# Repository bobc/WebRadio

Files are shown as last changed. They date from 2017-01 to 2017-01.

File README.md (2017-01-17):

# ARM Cortex-M3 WebRadio
The ARM WebRadio is an embedded Internet Radio based on an ARM Cortex-M3 Microcontroller and VS1053 Audio Codec.
The VS1053 can decode various audio formats, including Ogg Vorbis, MP3, AAC, WMA, FLAC, WAV, MIDI.

WebRadio

## Features
* Open-Source Hardware
  * Microcontroller: LM3S6950 ARM Cortex-M3 from Luminary Micro / TI
  * Audio Codec: VS1053 from VLSI
  * Display: S65 LCD with 176x132 pixel and 16bit color
  * microSD Socket
  * Rotary Encoder
  * IR Receiver (RC5)
  * PoE (Power over Ethernet)
* Open-Source Software
  * Play Shoutcast/Icecast and RTSP Streams
  * Play audio files from the memory card
  * Alarm Clock

## Hardware and Software
* WebRadio hardware dia
* [Schematics + Layout](https://github.com/watterott/WebRadio/tree/master/hardware)
* [Software/Firmware](https://github.com/watterott/WebRadio/tree/master/software)

## Videos
* [ARM WebRadio test buildup](http://www.youtube.com/watch?v=d3AU1xSci-s)
* [ARM WebRadio v1 prototype](http://www.youtube.com/watch?v=I5wxE6ul4LM)
* [ARM WebRadio v2 demo board](http://www.youtube.com/watch?v=boI7PvBz0HM)
* [ARM WebRadio v3](http://www.youtube.com/watch?v=70_Qk82P8Xw)

## Notes on this fork

The LM3S6950 is obsolete, there is no equivalent.
The S65 LCD may be hard to find as well.

I converted main and exp boards to KiCad 4.0.2.

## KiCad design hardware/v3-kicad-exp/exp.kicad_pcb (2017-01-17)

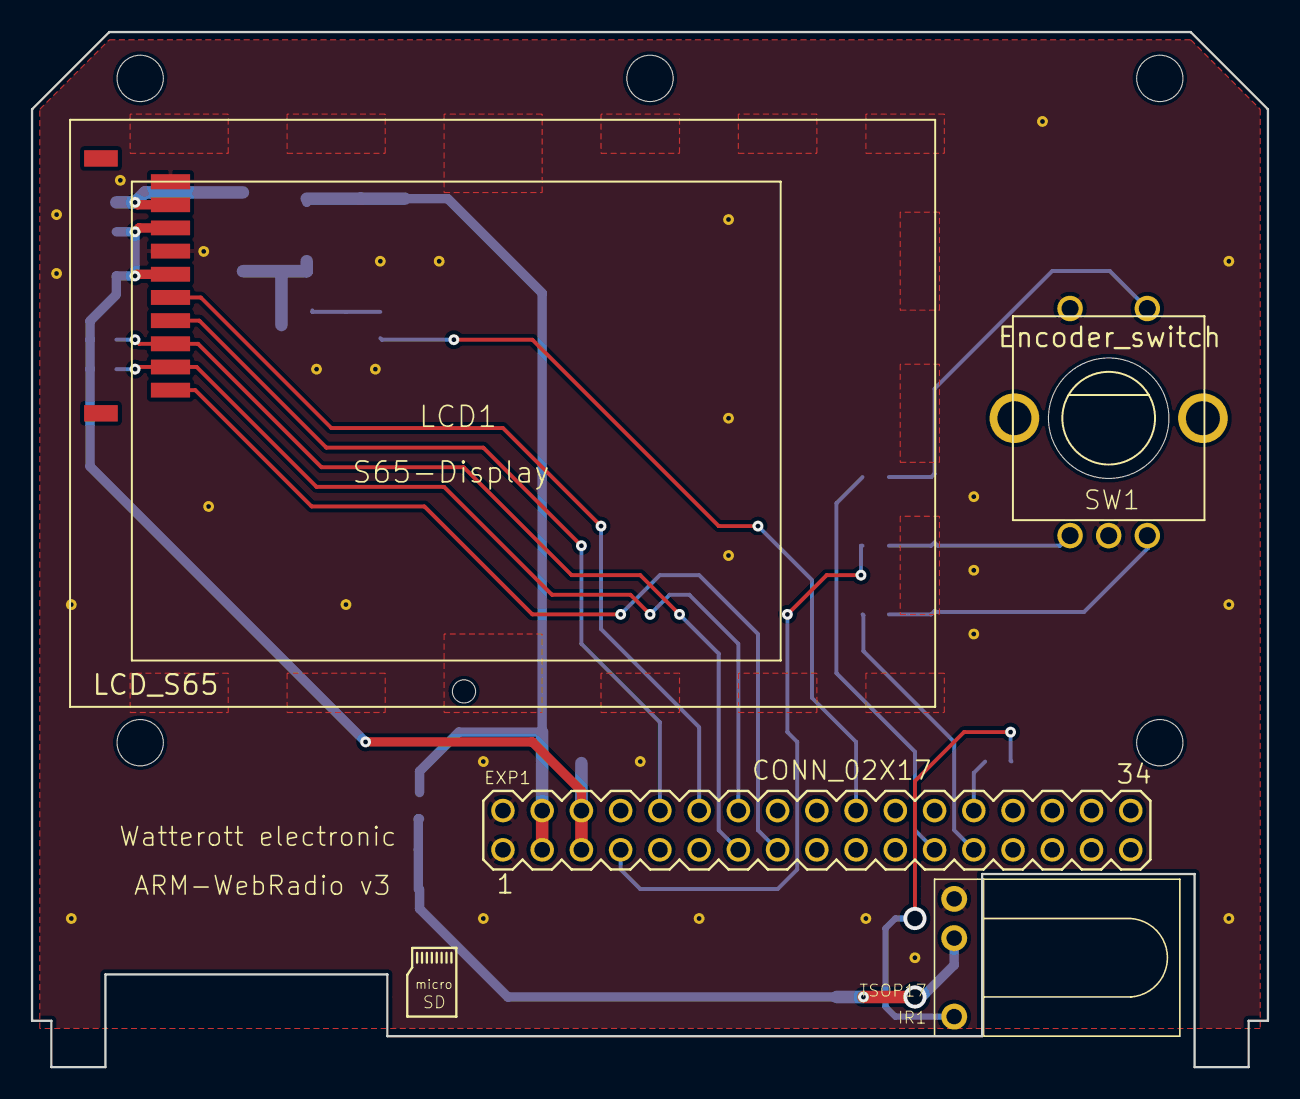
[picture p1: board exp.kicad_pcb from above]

Board: 2 copper layers, 80.0 x 67.0 mm, 63 parts (0 on the bottom side), 21 nets.

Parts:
@HOLE0, @HOLE1, @HOLE2, @HOLE3, @HOLE4, @HOLE5: HOLE
EXP1: CONN_02X17; MA17-2
EXP_C1, EXP_C2: 100nF; C0603
IR1: TSOP17
IR_C1: 100nF; C0603
IR_C2, IR_C3: 2uF; C0603K
IR_R1: 1k; R0603
IR_R2: 100; R0603
LCD1: LCD_S65; S65
LCD_C1, LCD_C2, LCD_C3, LCD_C4: 100nF; C0603
LCD_C5: 2uF; C0603K
LCD_D1: D; DO214AA
LCD_L1: 1-2mH; 50mA; L4532M
LCD_Q1: Q_NMOS_GSD; MICRO3
LCD_R1, LCD_R2, LCD_R4: 47k; R0603
LCD_R3: 100; R0603
SW1: Encoder_switch; ALPS_EC12E_SW
SW_C1, SW_C2, SW_C3: 2.2nF; C0603
SW_R1, SW_R2, SW_R3: 1k; R0603
V1, V2, V3, V4, V5, V6, V7, V8, V9, V10, V11, V12, V13, V14, V15, V16, V17, V18, V19, V20, V21, V22, V23, V24, V25, V26, V27, V28: via

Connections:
+3V3: EXP1.5, EXP1.6, EXP_C2.1, LCD1.1V8, LCD1.2V9, LCD_C1.1, LCD_C2.1, LCD_R1.2, LCD_R2.2
+5V: EXP1.3, EXP1.4, EXP_C1.1, IR_R2.2, LCD_C4.1, LCD_C5.1, LCD_L1.1
/ENC-A: EXP1.25, SW_R1.2
/ENC-B: EXP1.7, SW_R2.1
/ENC-SW: EXP1.23, SW_R3.2
/IR_RX: EXP1.26, IR_R1.1
/LCD_BACKLIGHT_PWM: EXP1.20, LCD_R3.1
/LCD_CS: EXP1.13, LCD1.CS, LCD_R2.1
/LCD_DATA: EXP1.12, LCD1.DATA
/LCD_RESET: EXP1.14, LCD1.RST, LCD_R1.1
/LCD_RS: EXP1.15, LCD1.RS
/LCD_SCK: EXP1.10, LCD1.CLK
GND: EXP1.1, EXP1.2, EXP_C1.2, EXP_C2.2, IR1.GND, IR_C1.2, IR_C2.2, IR_C3.2, LCD1.GND, LCD1.LED-, LCD_C1.2, LCD_C2.2, LCD_C3.2, LCD_C4.2, LCD_C5.2, LCD_Q1.2, LCD_R4.1, SW1.2, SW1.4, SW_C1.2, SW_C2.2, SW_C3.2, V1.1, V2.1, V3.1, V4.1, V5.1, V6.1, V7.1, V8.1, V9.1, V10.1, V11.1, V12.1, V13.1, V14.1, V15.1, V16.1, V17.1, V18.1, V19.1, V20.1, V21.1, V22.1, V23.1, V24.1, V25.1, V26.1, V27.1, V28.1
unnamed: IR1.VO, IR_R1.2
unnamed: IR1.VS, IR_C1.1, IR_C2.1, IR_C3.1, IR_R2.1
unnamed: LCD1.LED+, LCD_C3.1, LCD_D1.1
unnamed: LCD_D1.2, LCD_L1.2, LCD_Q1.3
unnamed: LCD_Q1.1, LCD_R3.2, LCD_R4.2
unnamed: SW1.1, SW_C1.1, SW_R1.1
unnamed: SW1.3, SW_C2.1, SW_R2.2
unnamed: SW1.5, SW_C3.1, SW_R3.1

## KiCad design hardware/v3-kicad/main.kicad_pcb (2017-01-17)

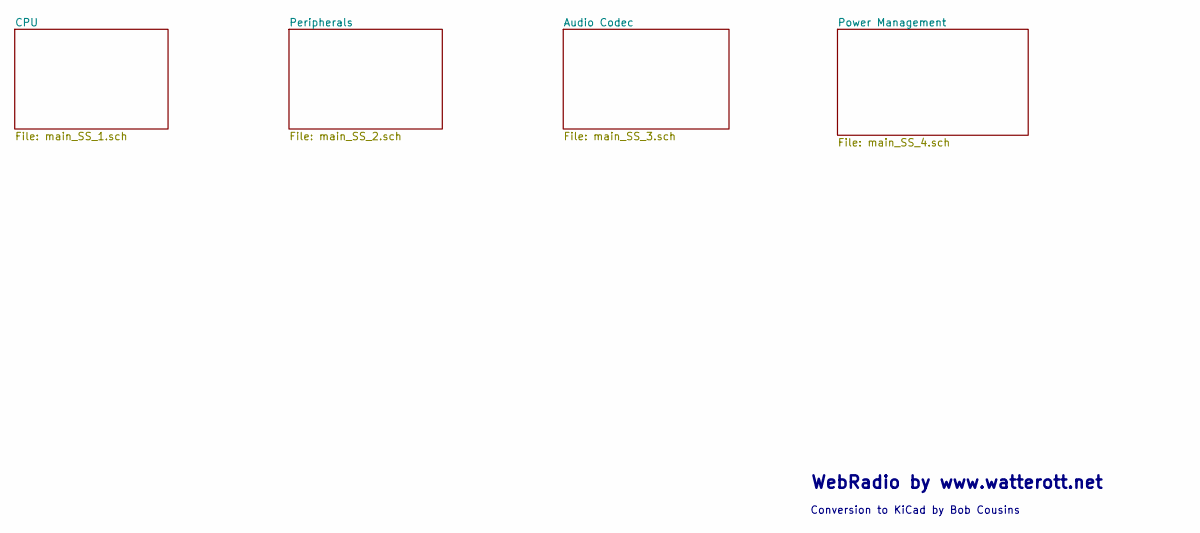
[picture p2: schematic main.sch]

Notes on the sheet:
WebRadio by www.watterott.net
Conversion to KiCad by Bob Cousins

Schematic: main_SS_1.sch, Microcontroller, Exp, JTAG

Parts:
ARM37: LM3S6950; LUMINARY_LQFP100
ARM_C1, ARM_C2, ARM_C3, ARM_C4: 18pF; RCL_C0603
ARM_C5, ARM_C6, ARM_C7, ARM_C8, ARM_C9, ARM_C10, ARM_C11, ARM_C12: 100nF; RCL_C0603
ARM_Q1: 8MHz; CRYSTAL_CS10
ARM_Q2: 25MHz; CRYSTAL_CS10
ARM_R1, ARM_R2, ARM_R3: 10k; RCL_R0603
ARM_R4: 12.4k; RCL_R0603
EXP37: CON-LSTB_MA17-2
EXP_C1, EXP_C2: 100nF; RCL_C0603
JTAG37: CON-LST_MA10-2_SMD
R1, R2: 470*; RCL_R0603
UART2: CON-LSTB_MA06-1
X1, X2, X3, X4: SPECIAL-PAD_SMD-ELLIPSE

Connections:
8: ARM37.70 (I2C0SCL/PB2), EXP37.8
13: ARM37.90 (C0+/C0O/PB6), EXP37.13
25: ARM37.11 (PHA0/PD1), EXP37.25
30: ARM37.22 (C2-/PC7), EXP37.30
+3V3: ARM37.3 (VCCA), ARM37.8 (VCC), ARM37.20 (VCC), ARM37.32 (VCC), ARM37.36 (VCCPHY), ARM37.44 (VCC), ARM37.56 (VCC), ARM37.68 (VCC), ARM37.81 (VCC), ARM37.83 (VCCPHY), ARM37.84 (VCCPHY), ARM37.93 (VCC), ARM37.98 (VCCA), ARM_C5.1, ARM_C6.1, ARM_C7.1, ARM_C8.1, ARM_R1.1, ARM_R2.2, ARM_R3.2, EXP37.5, EXP37.6, EXP_C2.2, JTAG37.1; also elsewhere on the board
+5V: EXP37.3, EXP37.4, EXP_C1.2; also elsewhere on the board
/main_SS_1/7: ARM37.47 (PHB0/PF0), EXP37.7
/main_SS_1/9: ARM37.71 (I2C0SDA/PB3), EXP37.9
/main_SS_1/14: ARM37.91 (C1-/PB5), EXP37.14
/main_SS_1/15: ARM37.92 (C0-/PB4), EXP37.15
/main_SS_1/16: ARM37.95 (CCP0/PD4), EXP37.16
/main_SS_1/17: ARM37.96 (CCP2/PD5), EXP37.17
/main_SS_1/18: ARM37.99 (FAULT/PD6), EXP37.18
/main_SS_1/19: ARM37.100 (IDX0/PD7), EXP37.19
/main_SS_1/20: ARM37.1 (PWM5/PE7), EXP37.20
/main_SS_1/21: ARM37.2 (PWM4/PE6), EXP37.21
/main_SS_1/22: ARM37.5 (PE5), EXP37.22
/main_SS_1/23: ARM37.6 (CCP3/PE4), EXP37.23
/main_SS_1/24: ARM37.10 (PWM0/PD0), EXP37.24
/main_SS_1/26: ARM37.12 (U1RX/PD2), EXP37.26
/main_SS_1/27: ARM37.13 (U1TX/PD3), EXP37.27
/main_SS_1/28: ARM37.18 (U2TX/PG1), EXP37.28, R2.1
/main_SS_1/29: ARM37.19 (U2RX/PG0), EXP37.29, R1.1
/main_SS_1/31: ARM37.23 (C2+/C2O/PC6), EXP37.31
/main_SS_1/32: ARM37.24 (C1+/C1O/PC5), EXP37.32
/main_SS_1/33: ARM37.25 (CCP5/PC4), EXP37.33
/main_SS_1/ERBIAS: ARM37.41 (ERBIAS), ARM_R4.1
/main_SS_1/MDIO: ARM37.58 (MDIO), ARM_R3.1
/main_SS_1/N$9: ARM37.48 (OSC0), ARM_C1.1, ARM_Q1.2
/main_SS_1/N$10: ARM37.49 (OSC1), ARM_C2.1, ARM_Q1.1
/main_SS_1/N$13: ARM37.17 (XTALNPHY), ARM_C4.1, ARM_Q2.1
/main_SS_1/N$14: ARM37.16 (XTALPPHY), ARM_C3.1, ARM_Q2.2
/main_SS_1/RESET: ARM37.64 (~RESET), ARM_R1.2
/main_SS_1/RXD: R2.2, UART2.5
/main_SS_1/TCK: ARM37.80 (TCK/SWCLK/PC0), JTAG37.9
/main_SS_1/TDI: ARM37.78 (TDI/PC2), JTAG37.5
/main_SS_1/TDO: ARM37.77 (TDO/SWO/PC3), JTAG37.13
/main_SS_1/TMS: ARM37.79 (TMS/SWDIO/PC1), JTAG37.7
/main_SS_1/TRST: ARM37.89 (TRST/PB7), ARM_R2.1, JTAG37.3
/main_SS_1/TXD: R1.2, UART2.4
FM_CS: ARM37.73 (SSI1FSS/PE1); also elsewhere on the board
GND: ARM37.4 (GNDA), ARM37.9 (GND), ARM37.15 (GND), ARM37.21 (GND), ARM37.33 (GND), ARM37.39 (GND), ARM37.42 (GNDPHY), ARM37.45 (GND), ARM37.50 (~WAKE), ARM37.54 (GND), ARM37.57 (GND), ARM37.63 (GND), ARM37.65 (CMOD0), ARM37.69 (GND), ARM37.76 (CMOD1), ARM37.82 (GND), ARM37.85 (GNDPHY), ARM37.86 (GNDPHY), ARM37.87 (GND), ARM37.94 (GND), ARM37.97 (GNDA), ARM_C1.2, ARM_C2.2, ARM_C3.2, ARM_C4.2, ARM_C5.2, ARM_C6.2, ARM_C7.2, ARM_C8.2, ARM_C9.2, ARM_C10.2, ARM_C11.2, ARM_C12.2, ARM_R4.2, EXP37.1, EXP37.2, EXP_C1.1, EXP_C2.1, JTAG37.4, JTAG37.6, JTAG37.8, JTAG37.10, JTAG37.12, JTAG37.14, JTAG37.16, JTAG37.18, JTAG37.20, UART2.1; also elsewhere on the board
LED1: ARM37.59 (LED0/PF3); also elsewhere on the board
LED2: ARM37.60 (LED1/PF2); also elsewhere on the board
RD+: ARM37.40 (RXIP); also elsewhere on the board
RD-: ARM37.37 (RXIN); also elsewhere on the board
SCK: ARM37.72 (SSI1CLK/PE0), EXP37.10; also elsewhere on the board
SD_CS: ARM37.67 (PWM3/PB1); also elsewhere on the board
SD_PWR: ARM37.66 (PWM2/PB0); also elsewhere on the board
SI: ARM37.75 (SSI1TX/PE3), EXP37.12; also elsewhere on the board
SO: ARM37.74 (SSI1RX/PE2), EXP37.11; also elsewhere on the board
TD+: ARM37.43 (TXOP); also elsewhere on the board
TD-: ARM37.46 (TXON); also elsewhere on the board
USB_PWR: ARM37.61 (PWM1/PF1); also elsewhere on the board
VCCIO: ARM37.7 (LDO), ARM37.14 (VCC25), ARM37.38 (VCC25), ARM37.62 (VCC25), ARM37.88 (VCC25), ARM_C9.1, ARM_C10.1, ARM_C11.1, ARM_C12.1
VS_CS: ARM37.34 (CCP1/PA6); also elsewhere on the board
VS_DCS: ARM37.29 (SSI0FSS/PA3); also elsewhere on the board
VS_DREQ: ARM37.27 (U0TX/PA1); also elsewhere on the board
VS_RST: ARM37.35 (CCP4/PA7); also elsewhere on the board
VS_SCK: ARM37.28 (SSI0CLK/PA2); also elsewhere on the board
VS_SI: ARM37.31 (SSI0TX/PA5); also elsewhere on the board
VS_SO: ARM37.30 (SSI0RX/PA4); also elsewhere on the board

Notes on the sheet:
CTS
3V3
GND
TxD
RxD
DTR
FTDI Basic Breakout

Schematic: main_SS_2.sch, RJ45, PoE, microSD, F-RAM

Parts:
FM37: FM25V...; RAMTRON_SO8
FM_C1: 100nF; RCL_C0603
FM_R1: 47k; RCL_R0603
POE37: TPS2375D; ETHERNET_SO08
POE_C1: 100nF; RCL_C1206
POE_CLA37: 4,3k; RCL_R0603
POE_D1: SMAJ58A; DIODE_DO214AA
POE_DET37: 24k; RCL_R0603
POE_ILM37: 100k; RCL_R0603
RJ37: RJ45-8-POEWE; ETHERNET_WE_POE
RJ_C1: 100nF; RCL_C0603
RJ_C2, RJ_C5, RJ_C6, RJ_C9: 10pF; RCL_C0603
RJ_C3, RJ_C4, RJ_C7, RJ_C8, RJ_C10: 10nF; RCL_C0603
RJ_R1, RJ_R2, RJ_R3, RJ_R4: 50; RCL_R0603
RJ_R5, RJ_R6: 470; RCL_R0603
RJ_R7: 100; RCL_R0603
SD37: MICRO-SD; SD-CARD_MICRO-SD
SD_C1, SD_C2: 100nF; RCL_C0603
SD_C3: 2uF; RCL_C0603
SD_Q1: P-CHN; IRF-SOT23_MICRO3
SD_R1, SD_R2, SD_R3, SD_R4, SD_R5: 47k; RCL_R0603

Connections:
+3V3: FM37.3 (-WP), FM37.7 (-HOLD), FM37.8 (VCC), FM_C1.1, FM_R1.2, RJ37.3 (RCT), RJ37.4 (TCT), RJ37.L1_P (LED1+), RJ37.L2_P (LED2+), RJ_C1.1, RJ_C3.2, RJ_C4.2, RJ_C7.2, RJ_C8.2, RJ_R1.2, RJ_R2.2, RJ_R3.2, RJ_R4.2, SD_C2.2, SD_C3.2, SD_Q1.2 (S), SD_R1.1; also elsewhere on the board
/main_SS_2/CLASS: POE37.2 (CLASS), POE_CLA37.2
/main_SS_2/DET: POE37.3 (DET), POE_DET37.2
/main_SS_2/ILM: POE37.1 (ILM), POE_ILM37.2
/main_SS_2/N$4: RJ37.L2_N (LED2-), RJ_R6.1
/main_SS_2/N$5: RJ37.L1_N (LED1-), RJ_R5.1
/main_SS_2/N$29: RJ_C10.1, RJ_R7.1
/main_SS_2/POE-: POE37.4 (POE-), POE_C1.2, POE_CLA37.1, POE_D1.A, POE_ILM37.1, RJ37.10 (POE-)
/main_SS_2/SD_1: SD37.1, SD_R5.2
/main_SS_2/SD_3V3: SD37.4, SD_C1.1, SD_Q1.3 (D), SD_R2.1, SD_R3.1, SD_R4.1, SD_R5.1
/main_SS_2/SD_8: SD37.8, SD_R2.2
/main_SS_2/SHIELD: RJ37.NC0 (SHIELD), RJ37.NC1 (SHIELD), RJ_R7.2
FM_CS: FM37.1 (-CS), FM_R1.1; also elsewhere on the board
GND: FM37.4 (GND), FM_C1.2, POE37.5 (RTN), RJ_C1.2, RJ_C2.1, RJ_C3.1, RJ_C4.1, RJ_C5.1, RJ_C6.1, RJ_C7.1, RJ_C8.1, RJ_C9.1, RJ_C10.2, SD37.6, SD_C1.2, SD_C2.1, SD_C3.1; also elsewhere on the board
LED1: RJ_R5.2; also elsewhere on the board
LED2: RJ_R6.2; also elsewhere on the board
POE+: RJ37.9 (POE+); also elsewhere on the board
PWR+: POE37.8 (POE+), POE_C1.1, POE_D1.C, POE_DET37.1; also elsewhere on the board
RD+: RJ37.1 (RD+), RJ_C2.2, RJ_R1.1; also elsewhere on the board
RD-: RJ37.2 (RD-), RJ_C5.2, RJ_R2.1; also elsewhere on the board
SCK: FM37.6 (CLK), SD37.5; also elsewhere on the board
SD_CS: SD37.2, SD_R4.2; also elsewhere on the board
SD_PWR: SD_Q1.1 (G), SD_R1.2; also elsewhere on the board
SI: FM37.5 (DI), SD37.3; also elsewhere on the board
SO: FM37.2 (DO), SD37.7, SD_R3.2; also elsewhere on the board
TD+: RJ37.5 (TD+), RJ_C6.2, RJ_R3.1; also elsewhere on the board
TD-: RJ37.6 (TD-), RJ_C9.2, RJ_R4.1; also elsewhere on the board

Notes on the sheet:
RJ45 + PoE
F-RAM (optional)
4k4
100k
25k
microSD

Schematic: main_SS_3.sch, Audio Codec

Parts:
I2S37: CON-LSTB_MA04-1
OUT37: 1503_09; AUDIO_1503_09
PWR37: CON-LSTB_MA04-1
PWR_C1, PWR_C2: 100nF; RCL_C0603
VS37: VS1053; VLSI_LQFP-48
VS_C1, VS_C2: 27pF; RCL_C0603
VS_C3, VS_C4: 10nF; RCL_C0603
VS_C5: 47nF; RCL_C0603
VS_C6: 1uF; RCL_C0603
VS_C7, VS_C8, VS_C9, VS_C10, VS_C11, VS_C12, VS_C13, VS_C14, VS_C15: 100nF; RCL_C0603
VS_CL2: 2.2nF; RCL_C0603
VS_CL37: 10uF; RCL_C1210
VS_CR2: 2.2nF; RCL_C0603
VS_CR37: 10uF; RCL_C1210
VS_GBUF37: 0*; RCL_R0603
VS_GND37: 0*; RCL_R0603
VS_Q1: 12.288MHz; CRYSTAL_SM49
VS_R1: 1M; RCL_R0603
VS_R2, VS_R3, VS_R9, VS_R10, VS_R11, VS_R12: 100k; RCL_R0603
VS_R4, VS_R5: 22; RCL_R0603
VS_R6: 10; RCL_R0603
VS_R7, VS_R8: 10k; RCL_R0603
VS_RL37: 470; RCL_R0603
VS_RR37: 470; RCL_R0603

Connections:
+1V8: VS37.5 (CVCC0), VS37.7 (CVCC1), VS37.24 (CVCC2), VS37.31 (CVCC3), VS_C10.1, VS_C11.1, VS_C12.1, VS_C13.1; also elsewhere on the board
+2V8: VS37.38 (AVCC0), VS37.43 (AVCC1), VS37.45 (AVCC2), VS_C14.1, VS_C15.1; also elsewhere on the board
+3V3: PWR37.2, PWR_C1.2, VS37.6 (IOVCC0), VS37.14 (IOVCC1), VS37.19 (IOVCC2), VS37.26 (RX), VS37.32 (TEST), VS_C7.1, VS_C8.1, VS_C9.1; also elsewhere on the board
+5V: PWR37.1, PWR_C2.2; also elsewhere on the board
/main_SS_3/GBUF: VS37.42 (GBUF), VS_GBUF37.1, VS_R6.2
/main_SS_3/I2S_LROUT: I2S37.1, VS37.36 (GPIO4), VS_R9.1
/main_SS_3/I2S_MCLK: I2S37.2, VS37.25 (GPIO5), VS_R10.1
/main_SS_3/I2S_SCLK: I2S37.3, VS37.11 (GPIO6), VS_R11.1
/main_SS_3/I2S_SDATA: I2S37.4, VS37.12 (GPIO7), VS_R12.1
/main_SS_3/LEFT: VS37.46 (LEFT), VS_R4.2, VS_RL37.1
/main_SS_3/N$3: VS37.33 (GPIO0), VS37.34 (GPIO1), VS_R3.2
/main_SS_3/N$6: VS37.9 (GPIO2), VS37.10 (GPIO3), VS_R2.2
/main_SS_3/N$8: VS37.18 (XTALI), VS_C2.1, VS_Q1.1, VS_R1.2
/main_SS_3/N$11: VS37.17 (XTALO), VS_C1.1, VS_Q1.2, VS_R1.1
/main_SS_3/N$18: OUT37.1, VS_GBUF37.2, VS_GND37.1
/main_SS_3/N$19: OUT37.3, OUT37.5, VS_CR37.2, VS_R7.1
/main_SS_3/N$20: OUT37.2, OUT37.4, VS_CL37.2, VS_R8.1
/main_SS_3/N$21: VS_CR2.1, VS_CR37.1, VS_RR37.2
/main_SS_3/N$22: VS_CL2.1, VS_CL37.1, VS_RL37.2
/main_SS_3/N$31: VS_C3.2, VS_R4.1
/main_SS_3/N$32: VS_C4.2, VS_R5.1
/main_SS_3/N$33: VS_C5.2, VS_R6.1
/main_SS_3/RCAP: VS37.44 (RCAP), VS_C6.2
/main_SS_3/RIGHT: VS37.39 (RIGHT), VS_R5.2, VS_RR37.1
AGND: VS37.37 (AGND0), VS37.40 (AGND1), VS37.41 (AGND2), VS37.47 (AGND3), VS_C3.1, VS_C4.1, VS_C5.1, VS_C6.1, VS_C14.2, VS_C15.2, VS_CL2.2, VS_CR2.2, VS_GND37.2, VS_R7.2, VS_R8.2; also elsewhere on the board
GND: PWR37.3, PWR37.4, PWR_C1.1, PWR_C2.1, VS37.4 (GND0), VS37.16 (GND1), VS37.20 (GND2), VS37.21 (GND3), VS37.22 (GND4), VS37.35 (GND5), VS_C1.2, VS_C2.2, VS_C7.2, VS_C8.2, VS_C9.2, VS_C10.2, VS_C11.2, VS_C12.2, VS_C13.2, VS_R2.1, VS_R3.1, VS_R9.2, VS_R10.2, VS_R11.2, VS_R12.2; also elsewhere on the board
VS_CS: VS37.23 (~CS); also elsewhere on the board
VS_DCS: VS37.13 (~DCS); also elsewhere on the board
VS_DREQ: VS37.8 (~DREQ); also elsewhere on the board
VS_RST: VS37.3 (~RESET); also elsewhere on the board
VS_SCK: VS37.28 (SCLK); also elsewhere on the board
VS_SI: VS37.29 (SI); also elsewhere on the board
VS_SO: VS37.30 (SO); also elsewhere on the board

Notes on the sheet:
Normal Line-Out
Line-Out for Headphones
VS_GND
VS_GBUF
VS_RR
VS_RL
VS_CL
VS_CR
not mounted
470
10uF
shorted
VS_CR2
VS_CL2
2.2nF
Note: For VS1033 U4 has to be a 2.5V regulator.
Line-Out = green
(Dont use with USB powered speakers)
Further Infos: VLSI AppNote: Connecting analog outputs
GND-AGND

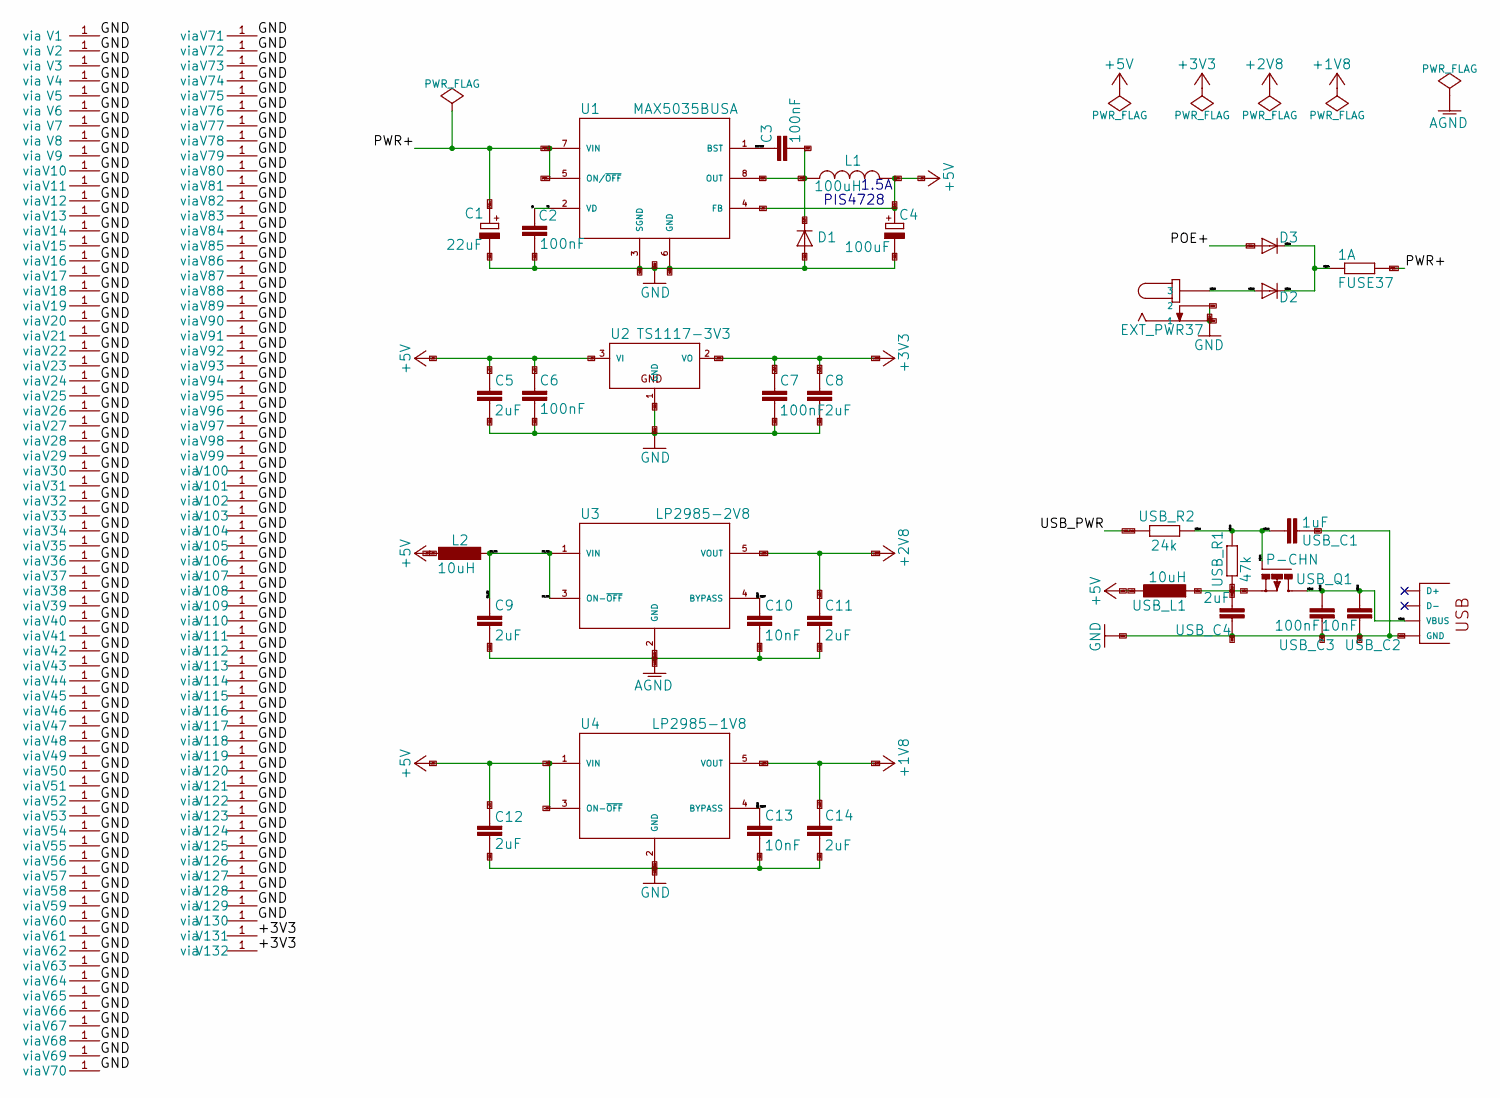
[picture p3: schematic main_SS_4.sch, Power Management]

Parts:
C1: 22uF; RCL_153CLV-0810
C2, C3, C6, C7: 100nF; RCL_C0603
C4: 100uF; RCL_153CLV-0810
C5, C8, C9, C11, C12, C14: 2uF; RCL_C0603
C10, C13: 10nF; RCL_C0603
D1, D2, D3: DIODE_DO214AA
EXT_PWR37: CON-JACK_SPC4077
FUSE37: 1A; RCL_R1206
L1: 100uH; VOLTAGE-REG_CDRH
L2: 10uH; RCL_L3230M
U1: MAX5035BUSA; VOLTAGE-REG_SO8
U2: TS1117-3V3; VOLTAGE-REG_SOT223
U3: LP2985-2V8; VOLTAGE-REG_SOT23-5
U4: LP2985-1V8; VOLTAGE-REG_SOT23-5
USB37: USB-A-S; CON-USB_USB-A-S
USB_C1: 1uF; RCL_C0603
USB_C2: 10nF; RCL_C0603
USB_C3: 100nF; RCL_C0603
USB_C4: 2uF; RCL_C0805
USB_L1: 10uH; RCL_L3230M
USB_Q1: P-CHN; IRF-SOT23_MICRO3
USB_R1: 47k; RCL_R0603
USB_R2: 24k; RCL_R0603
V1, V2, V3, V4, V5, V6, V7, V8, V9, V10, V11, V12, V13, V14, V15, V16, V17, V18, V19, V20, V21, V22, V23, V24, V25, V26, V27, V28, V29, V30, V31, V32, V33, V34, V35, V36, V37, V38, V39, V40, V41, V42, V43, V44, V45, V46, V47, V48, V49, V50, V51, V52, V53, V54, V55, V56, V57, V58, V59, V60, V61, V62, V63, V64, V65, V66, V67, V68, V69, V70, V71, V72, V73, V74, V75, V76, V77, V78, V79, V80, V81, V82, V83, V84, V85, V86, V87, V88, V89, V90, V91, V92, V93, V94, V95, V96, V97, V98, V99, V100, V101, V102, V103, V104, V105, V106, V107, V108, V109, V110, V111, V112, V113, V114, V115, V116, V117, V118, V119, V120, V121, V122, V123, V124, V125, V126, V127, V128, V129, V130, V131, V132: via

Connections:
+1V8: C14.1, U4.5 (VOUT); also elsewhere on the board
+2V8: C11.1, U3.5 (VOUT); also elsewhere on the board
+3V3: C7.1, C8.1, U2.2 (VO), V131.1, V132.1; also elsewhere on the board
+5V: C4.+, C5.1, C6.2, C12.2, L1.2, L2.1, U1.4 (FB), U2.3 (VI), U4.1 (VIN), U4.3 (ON-~OFF), USB_L1.1; also elsewhere on the board
/main_SS_4/5V_VIN: C9.2, L2.2, U3.1 (VIN), U3.3 (ON-~OFF)
/main_SS_4/BST: C3.1, U1.1 (BST)
/main_SS_4/N$12: USB37.VBUS, USB_C2.1, USB_C3.1, USB_Q1.3 (D)
/main_SS_4/N$16: USB_C1.2, USB_Q1.1 (G), USB_R1.2, USB_R2.1
/main_SS_4/N$23: D2.A, EXT_PWR37.3
/main_SS_4/N$24: D2.C, D3.C, FUSE37.1
/main_SS_4/N$27: C10.1, U3.4 (BYPASS)
/main_SS_4/N$28: C13.1, U4.4 (BYPASS)
/main_SS_4/VD: C2.1, U1.2 (VD)
AGND: C9.1, C10.2, C11.2, U3.2 (GND); also elsewhere on the board
GND: C1.-, C2.2, C4.-, C5.2, C6.1, C7.2, C8.2, C12.1, C13.2, C14.2, D1.A, EXT_PWR37.1, EXT_PWR37.2, U1.3 (SGND), U1.6 (GND), U2.1 (GND), U4.2 (GND), USB37.GND, USB_C1.1, USB_C2.2, USB_C3.2, USB_C4.1, V1.1, V2.1, V3.1, V4.1, V5.1, V6.1, V7.1, V8.1, V9.1, V10.1, V11.1, V12.1, V13.1, V14.1, V15.1, V16.1, V17.1, V18.1, V19.1, V20.1, V21.1, V22.1, V23.1, V24.1, V25.1, V26.1, V27.1, V28.1, V29.1, V30.1, V31.1, V32.1, V33.1, V34.1, V35.1, V36.1, V37.1, V38.1, V39.1, V40.1, V41.1, V42.1, V43.1, V44.1, V45.1, V46.1, V47.1, V48.1, V49.1, V50.1, V51.1, V52.1, V53.1, V54.1, V55.1, V56.1, V57.1, V58.1, V59.1, V60.1, V61.1, V62.1, V63.1, V64.1, V65.1, V66.1, V67.1, V68.1, V69.1, V70.1, V71.1, V72.1, V73.1, V74.1, V75.1, V76.1, V77.1, V78.1, V79.1, V80.1, V81.1, V82.1, V83.1, V84.1, V85.1, V86.1, V87.1, V88.1, V89.1, V90.1, V91.1, V92.1, V93.1, V94.1, V95.1, V96.1, V97.1, V98.1, V99.1, V100.1, V101.1, V102.1, V103.1, V104.1, V105.1, V106.1, V107.1, V108.1, V109.1, V110.1, V111.1, V112.1, V113.1, V114.1, V115.1, V116.1, V117.1, V118.1, V119.1, V120.1, V121.1, V122.1, V123.1, V124.1, V125.1, V126.1, V127.1, V128.1, V129.1, V130.1; also elsewhere on the board
unnamed: USB_C4.2, USB_L1.2, USB_Q1.2 (S), USB_R1.1
OUT: C3.2, D1.C, L1.1, U1.8 (OUT)
POE+: D3.A; also elsewhere on the board
PWR+: C1.+, FUSE37.2, U1.5 (ON/~OFF), U1.7 (VIN); also elsewhere on the board
USB_PWR: USB_R2.2; also elsewhere on the board

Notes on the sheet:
1.5A
PIS4728

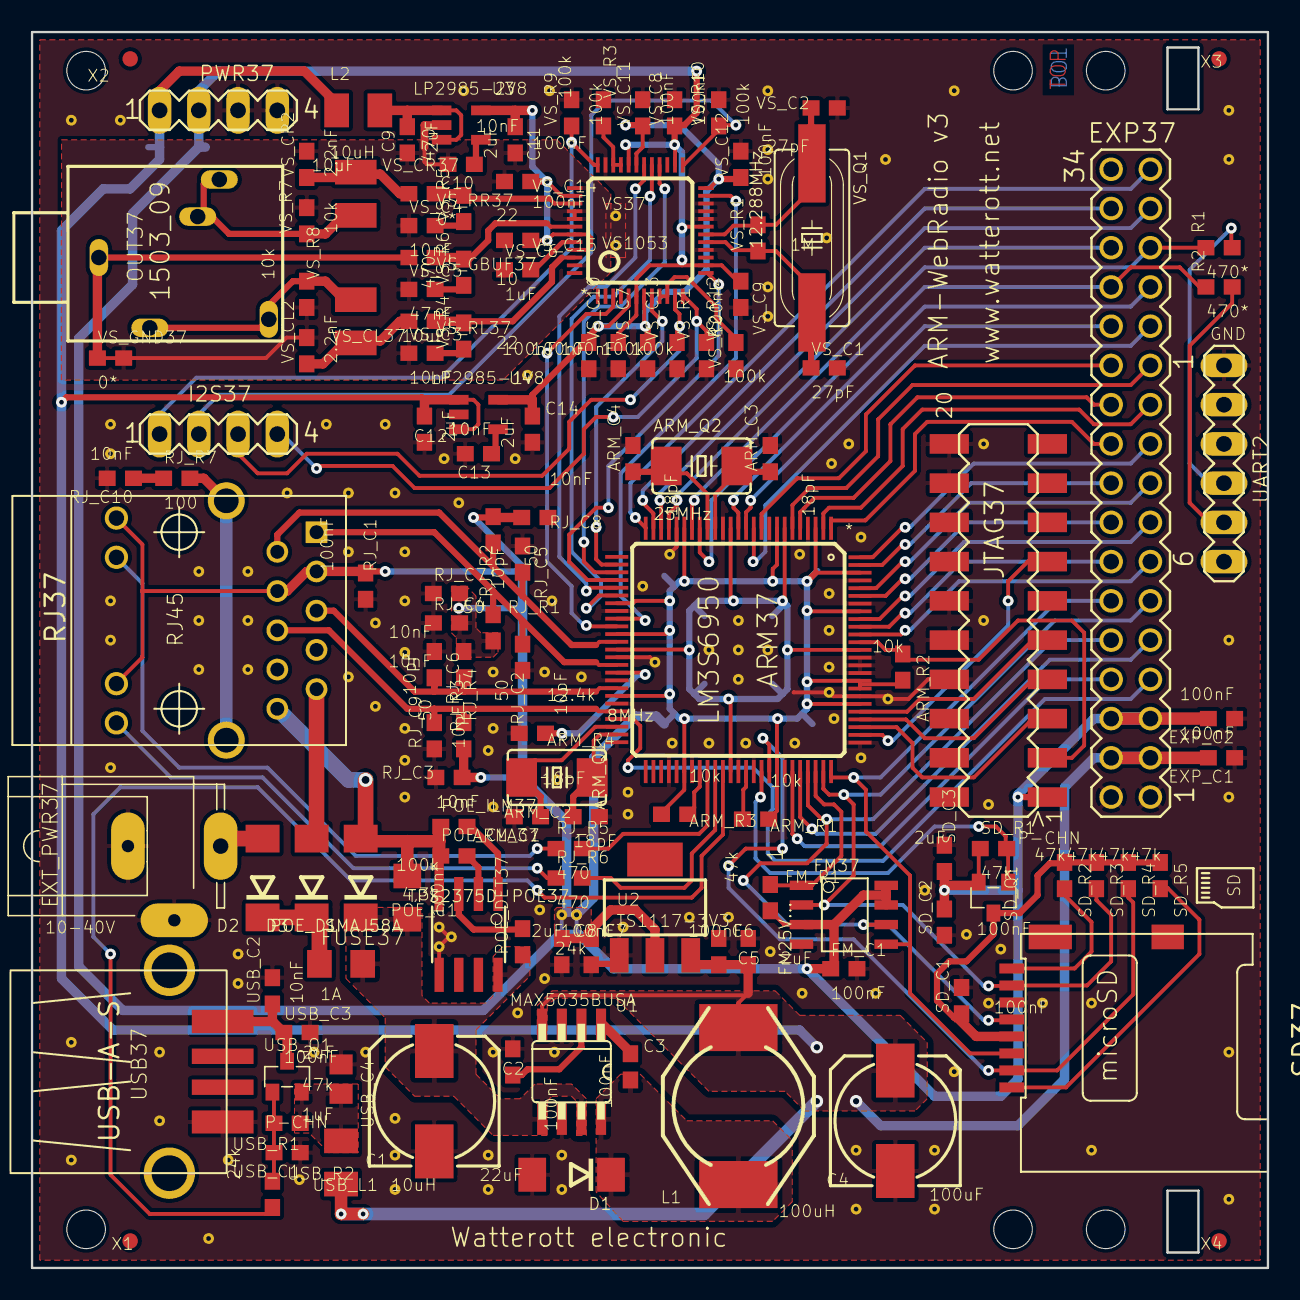
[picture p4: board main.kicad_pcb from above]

Board: 2 copper layers, 80.0 x 80.0 mm, 281 parts (0 on the bottom side), 109 nets.

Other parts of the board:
@HOLE0, @HOLE1, @HOLE2, @HOLE3, @HOLE4, @HOLE5: (no value)

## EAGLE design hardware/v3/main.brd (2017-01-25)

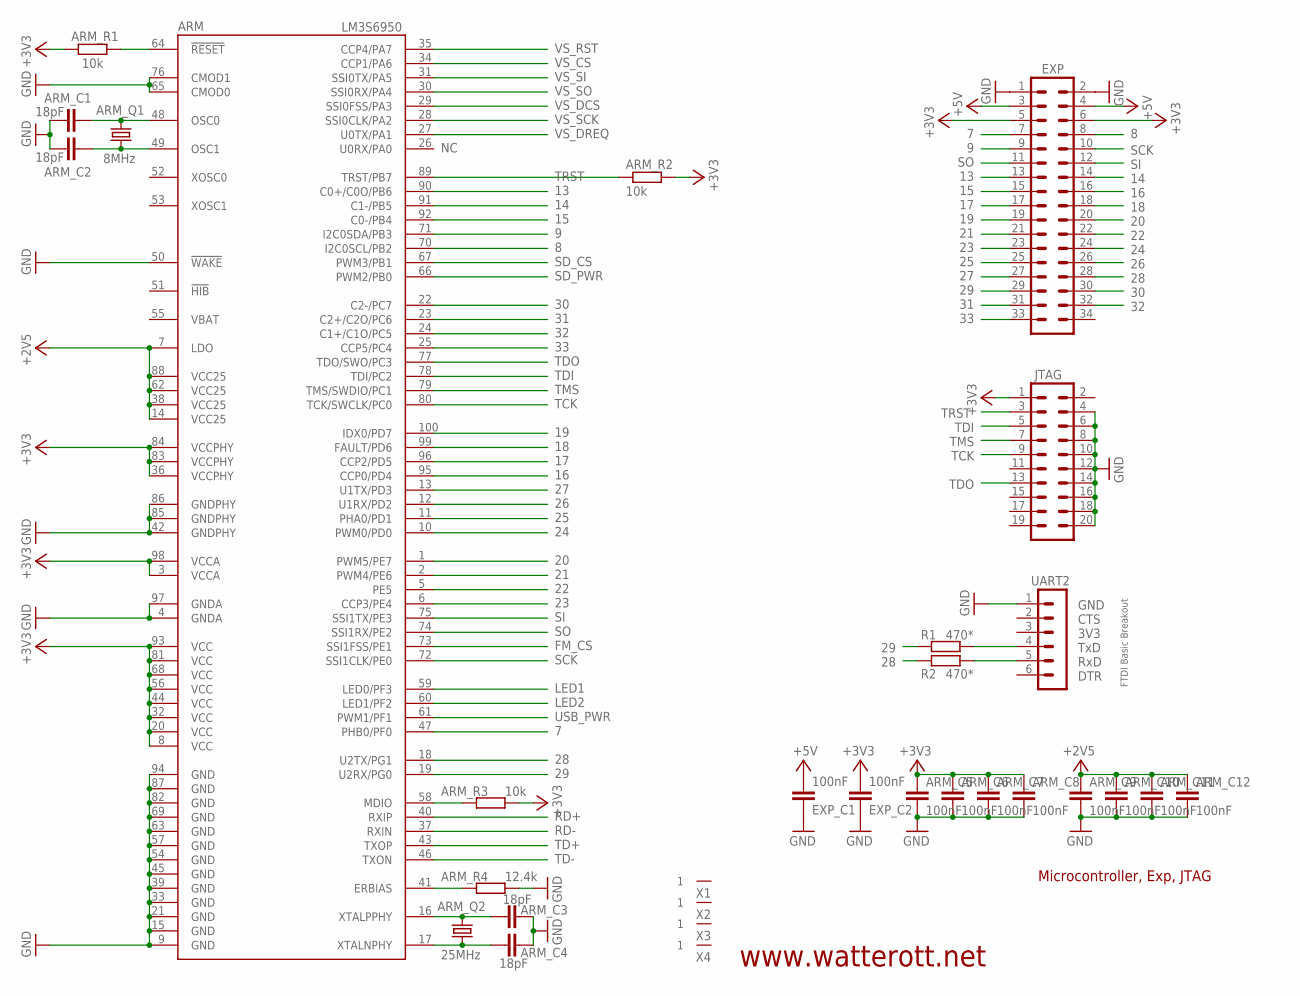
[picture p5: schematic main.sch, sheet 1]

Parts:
ARM: LM3S6950; LQFP100
ARM_C1, ARM_C2, ARM_C3, ARM_C4: 18pF; C0603
ARM_C5, ARM_C6, ARM_C7, ARM_C8, ARM_C9, ARM_C10, ARM_C11, ARM_C12: 100nF; C0603
ARM_Q1: 8MHz; CS10
ARM_Q2: 25MHz; CS10
ARM_R1, ARM_R2, ARM_R3: 10k; R0603
ARM_R4: 12.4k; R0603
EXP: MA17-2
EXP_C1, EXP_C2: 100nF; C0603
JTAG: MA10-2SMD; MA10-2_SMD
R1, R2: 470*; R0603
UART2: MA06-1
X1, X2, X3, X4: ELLIPTICAL-PADS; SMD-ELLIPSE

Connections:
7: ARM.47 (PHB0/PF0), EXP.7
8: ARM.70 (I2C0SCL/PB2), EXP.8
9: ARM.71 (I2C0SDA/PB3), EXP.9
13: ARM.90 (C0+/C0O/PB6), EXP.13
14: ARM.91 (C1-/PB5), EXP.14
15: ARM.92 (C0-/PB4), EXP.15
16: ARM.95 (CCP0/PD4), EXP.16
17: ARM.96 (CCP2/PD5), EXP.17
18: ARM.99 (FAULT/PD6), EXP.18
19: ARM.100 (IDX0/PD7), EXP.19
20: ARM.1 (PWM5/PE7), EXP.20
21: ARM.2 (PWM4/PE6), EXP.21
22: ARM.5 (PE5), EXP.22
23: ARM.6 (CCP3/PE4), EXP.23
24: ARM.10 (PWM0/PD0), EXP.24
25: ARM.11 (PHA0/PD1), EXP.25
26: ARM.12 (U1RX/PD2), EXP.26
27: ARM.13 (U1TX/PD3), EXP.27
28: ARM.18 (U2TX/PG1), EXP.28, R2.1
29: ARM.19 (U2RX/PG0), EXP.29, R1.1
30: ARM.22 (C2-/PC7), EXP.30
31: ARM.23 (C2+/C2O/PC6), EXP.31
32: ARM.24 (C1+/C1O/PC5), EXP.32
33: ARM.25 (CCP5/PC4), EXP.33
+2V5: ARM.7 (LDO), ARM.14 (VCC25), ARM.38 (VCC25), ARM.62 (VCC25), ARM.88 (VCC25), ARM_C9.1, ARM_C10.1, ARM_C11.1, ARM_C12.1
+3V3: ARM.3 (VCCA), ARM.8 (VCC), ARM.20 (VCC), ARM.32 (VCC), ARM.36 (VCCPHY), ARM.44 (VCC), ARM.56 (VCC), ARM.68 (VCC), ARM.81 (VCC), ARM.83 (VCCPHY), ARM.84 (VCCPHY), ARM.93 (VCC), ARM.98 (VCCA), ARM_C5.1, ARM_C6.1, ARM_C7.1, ARM_C8.1, ARM_R1.1, ARM_R2.2, ARM_R3.2, EXP.5, EXP.6, EXP_C2.2, JTAG.1; also elsewhere on the board
+5V: EXP.3, EXP.4, EXP_C1.2; also elsewhere on the board
ERBIAS: ARM.41 (ERBIAS), ARM_R4.1
FM_CS: ARM.73 (SSI1FSS/PE1); also elsewhere on the board
GND: ARM.4 (GNDA), ARM.9 (GND), ARM.15 (GND), ARM.21 (GND), ARM.33 (GND), ARM.39 (GND), ARM.42 (GNDPHY), ARM.45 (GND), ARM.50 (!WAKE), ARM.54 (GND), ARM.57 (GND), ARM.63 (GND), ARM.65 (CMOD0), ARM.69 (GND), ARM.76 (CMOD1), ARM.82 (GND), ARM.85 (GNDPHY), ARM.86 (GNDPHY), ARM.87 (GND), ARM.94 (GND), ARM.97 (GNDA), ARM_C1.2, ARM_C2.2, ARM_C3.2, ARM_C4.2, ARM_C5.2, ARM_C6.2, ARM_C7.2, ARM_C8.2, ARM_C9.2, ARM_C10.2, ARM_C11.2, ARM_C12.2, ARM_R4.2, EXP.1, EXP.2, EXP_C1.1, EXP_C2.1, JTAG.4, JTAG.6, JTAG.8, JTAG.10, JTAG.12, JTAG.14, JTAG.16, JTAG.18, JTAG.20, UART2.1; also elsewhere on the board
LED1: ARM.59 (LED0/PF3); also elsewhere on the board
LED2: ARM.60 (LED1/PF2); also elsewhere on the board
MDIO: ARM.58 (MDIO), ARM_R3.1
unnamed: ARM.48 (OSC0), ARM_C1.1, ARM_Q1.2
unnamed: ARM.49 (OSC1), ARM_C2.1, ARM_Q1.1
unnamed: ARM.17 (XTALNPHY), ARM_C4.1, ARM_Q2.1
unnamed: ARM.16 (XTALPPHY), ARM_C3.1, ARM_Q2.2
RD+: ARM.40 (RXIP); also elsewhere on the board
RD-: ARM.37 (RXIN); also elsewhere on the board
RESET: ARM.64 (!RESET), ARM_R1.2
RXD: R2.2, UART2.5
SCK: ARM.72 (SSI1CLK/PE0), EXP.10; also elsewhere on the board
SD_CS: ARM.67 (PWM3/PB1); also elsewhere on the board
SD_PWR: ARM.66 (PWM2/PB0); also elsewhere on the board
SI: ARM.75 (SSI1TX/PE3), EXP.12; also elsewhere on the board
SO: ARM.74 (SSI1RX/PE2), EXP.11; also elsewhere on the board
TCK: ARM.80 (TCK/SWCLK/PC0), JTAG.9
TD+: ARM.43 (TXOP); also elsewhere on the board
TD-: ARM.46 (TXON); also elsewhere on the board
TDI: ARM.78 (TDI/PC2), JTAG.5
TDO: ARM.77 (TDO/SWO/PC3), JTAG.13
TMS: ARM.79 (TMS/SWDIO/PC1), JTAG.7
TRST: ARM.89 (TRST/PB7), ARM_R2.1, JTAG.3
TXD: R1.2, UART2.4
USB_PWR: ARM.61 (PWM1/PF1); also elsewhere on the board
VBAT: ARM.55 (VBAT)
VS_CS: ARM.34 (CCP1/PA6); also elsewhere on the board
VS_DCS: ARM.29 (SSI0FSS/PA3); also elsewhere on the board
VS_DREQ: ARM.27 (U0TX/PA1); also elsewhere on the board
VS_RST: ARM.35 (CCP4/PA7); also elsewhere on the board
VS_SCK: ARM.28 (SSI0CLK/PA2); also elsewhere on the board
VS_SI: ARM.31 (SSI0TX/PA5); also elsewhere on the board
VS_SO: ARM.30 (SSI0RX/PA4); also elsewhere on the board

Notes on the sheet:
Microcontroller, Exp, JTAG
www.watterott.net
CTS
3V3
GND
TxD
RxD
DTR
FTDI Basic Breakout

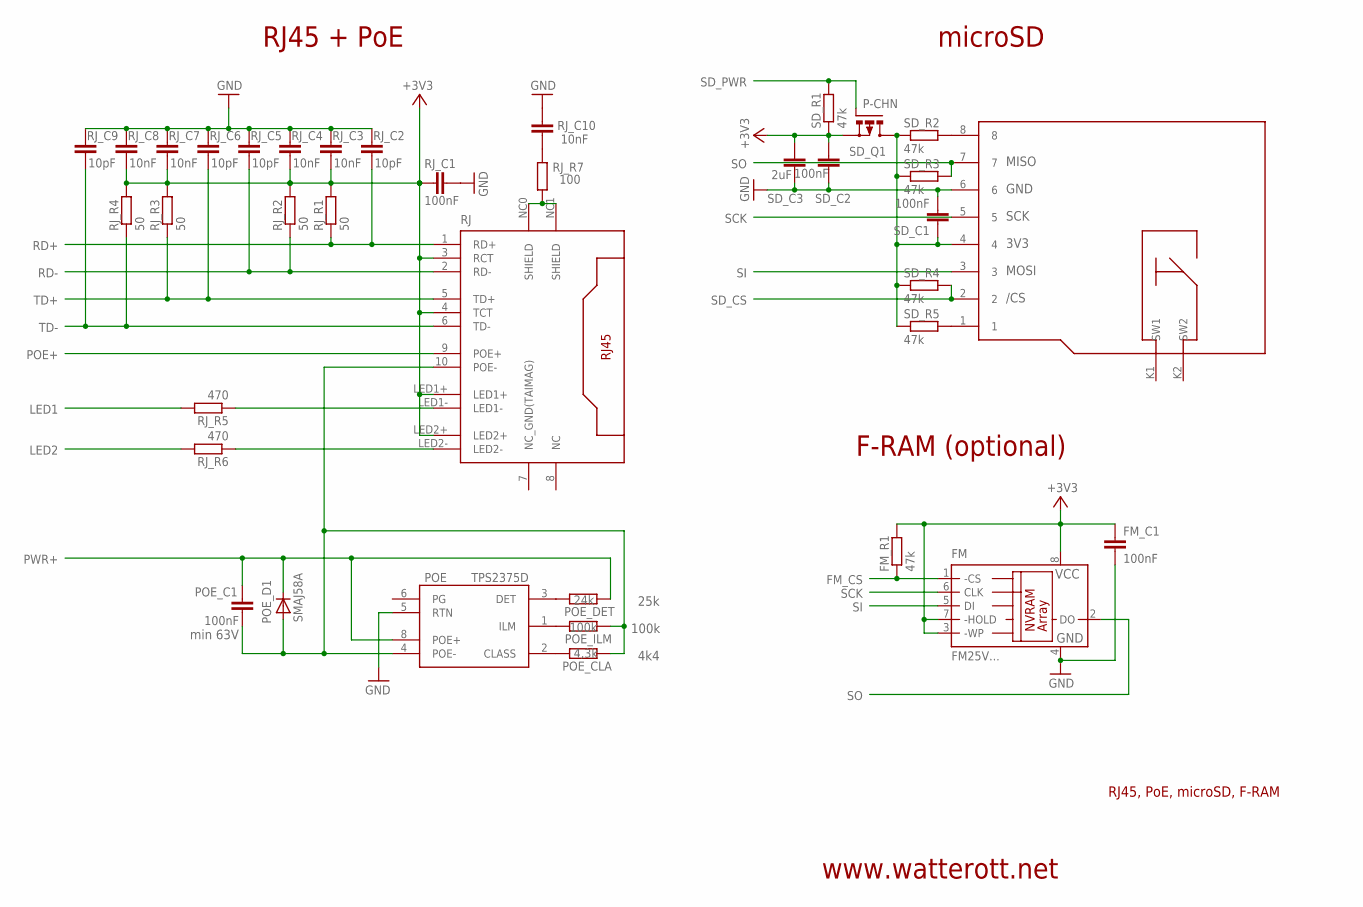
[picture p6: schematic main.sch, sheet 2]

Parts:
FM: FM25V...; SO8
FM_C1: 100nF; C0603
FM_R1: 47k; R0603
POE: TPS2375D; SO08
POE_C1: 100nF; C1206; VOLTAGE min 63V
POE_CLA: 4,3k; R0603
POE_D1: SMAJ58A; DO214AA
POE_DET: 24k; R0603
POE_ILM: 100k; R0603
RJ: RJ45-8-POEWE; WE_POE
RJ_C1: 100nF; C0603
RJ_C2, RJ_C5, RJ_C6, RJ_C9: 10pF; C0603
RJ_C3, RJ_C4, RJ_C7, RJ_C8, RJ_C10: 10nF; C0603
RJ_R1, RJ_R2, RJ_R3, RJ_R4: 50; R0603
RJ_R5, RJ_R6: 470; R0603
RJ_R7: 100; R0603
SD: MICRO-SD
SD_C1, SD_C2: 100nF; C0603
SD_C3: 2uF; C0603
SD_Q1: P-CHN; MICRO3
SD_R1, SD_R2, SD_R3, SD_R4, SD_R5: 47k; R0603

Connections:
+3V3: FM.3 (-WP), FM.7 (-HOLD), FM.8 (VCC), FM_C1.1, FM_R1.2, RJ.3 (RCT), RJ.4 (TCT), RJ.LED1+, RJ.LED2+, RJ_C1.1, RJ_C3.2, RJ_C4.2, RJ_C7.2, RJ_C8.2, RJ_R1.2, RJ_R2.2, RJ_R3.2, RJ_R4.2, SD_C2.2, SD_C3.2, SD_Q1.2 (S), SD_R1.1; also elsewhere on the board
CLASS: POE.2 (CLASS), POE_CLA.2
DET: POE.3 (DET), POE_DET.2
FM_CS: FM.1 (-CS), FM_R1.1; also elsewhere on the board
GND: FM.4 (GND), FM_C1.2, POE.5 (RTN), RJ_C1.2, RJ_C2.1, RJ_C3.1, RJ_C4.1, RJ_C5.1, RJ_C6.1, RJ_C7.1, RJ_C8.1, RJ_C9.1, RJ_C10.2, SD.6, SD_C1.2, SD_C2.1, SD_C3.1; also elsewhere on the board
ILM: POE.1 (ILM), POE_ILM.2
LED1: RJ_R5.2; also elsewhere on the board
LED2: RJ_R6.2; also elsewhere on the board
unnamed: RJ.LED2-, RJ_R6.1
unnamed: RJ.LED1-, RJ_R5.1
unnamed: RJ_C10.1, RJ_R7.1
NC: RJ.8 (NC)
NC_GND(TAIMAG): RJ.7 (NC_GND(TAIMAG))
POE+: RJ.9 (POE+); also elsewhere on the board
POE-: POE.4 (POE-), POE_C1.2, POE_CLA.1, POE_D1.A, POE_ILM.1, RJ.10 (POE-)
PWR+: POE.8 (POE+), POE_C1.1, POE_D1.C, POE_DET.1; also elsewhere on the board
RD+: RJ.1 (RD+), RJ_C2.2, RJ_R1.1; also elsewhere on the board
RD-: RJ.2 (RD-), RJ_C5.2, RJ_R2.1; also elsewhere on the board
SCK: FM.6 (CLK), SD.5; also elsewhere on the board
SD_1: SD.1, SD_R5.2
SD_3V3: SD.4, SD_C1.1, SD_Q1.3 (D), SD_R2.1, SD_R3.1, SD_R4.1, SD_R5.1
SD_8: SD.8, SD_R2.2
SD_CS: SD.2, SD_R4.2; also elsewhere on the board
SD_PWR: SD_Q1.1 (G), SD_R1.2; also elsewhere on the board
SHIELD: RJ.NC0 (SHIELD), RJ.NC1 (SHIELD), RJ_R7.2
SI: FM.5 (DI), SD.3; also elsewhere on the board
SO: FM.2 (DO), SD.7, SD_R3.2; also elsewhere on the board
TD+: RJ.5 (TD+), RJ_C6.2, RJ_R3.1; also elsewhere on the board
TD-: RJ.6 (TD-), RJ_C9.2, RJ_R4.1; also elsewhere on the board

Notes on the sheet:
RJ45, PoE, microSD, F-RAM
RJ45 + PoE
F-RAM (optional)
www.watterott.net
4k4
100k
25k
microSD

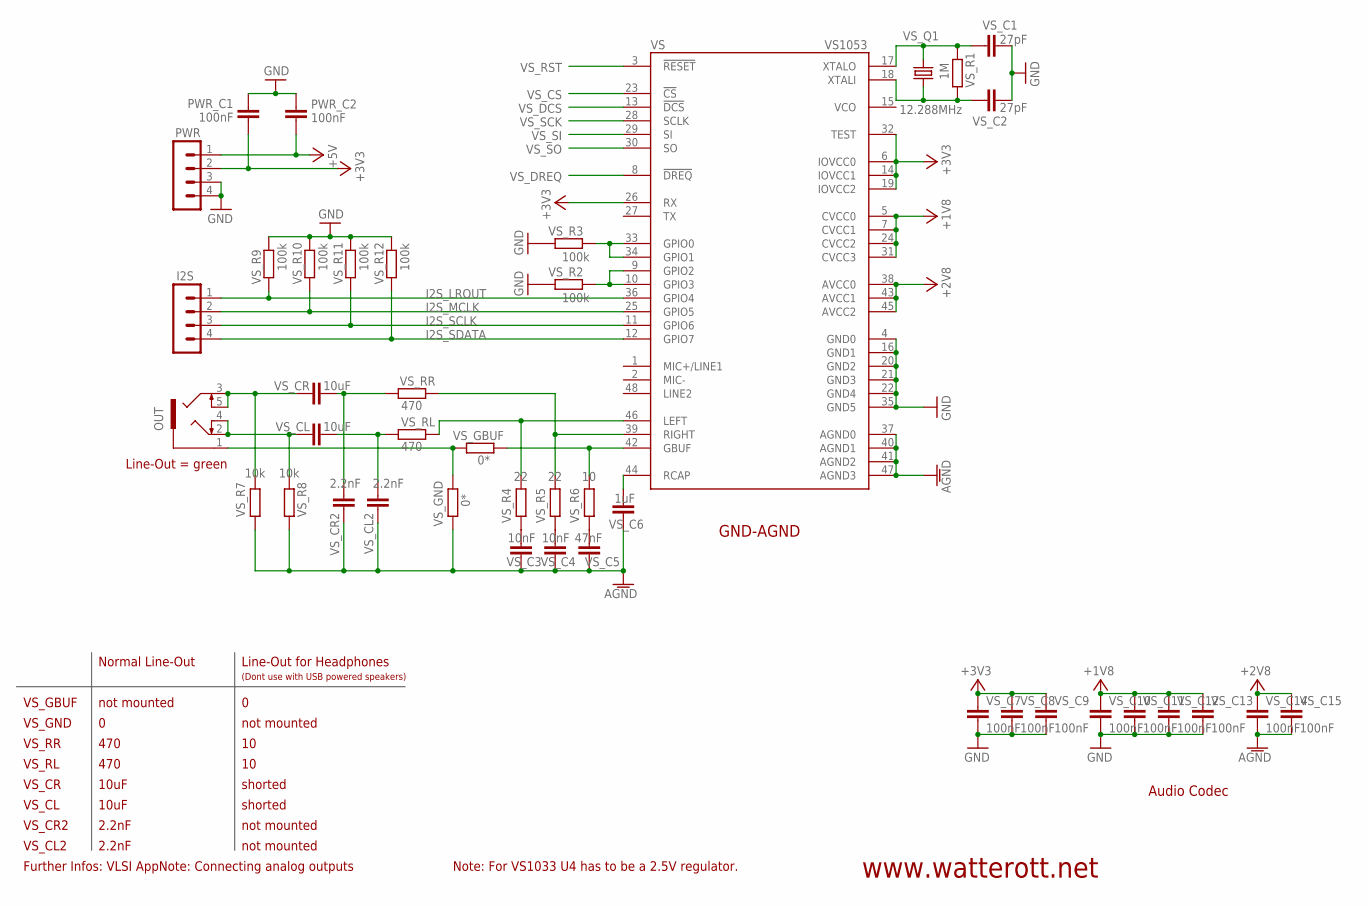
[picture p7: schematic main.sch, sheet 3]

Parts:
I2S: MA04-1
OUT: 1503_09
PWR: MA04-1
PWR_C1, PWR_C2: 100nF; C0603
VS: VS1053; LQFP-48
VS_C1, VS_C2: 27pF; C0603
VS_C3, VS_C4: 10nF; C0603
VS_C5: 47nF; C0603
VS_C6: 1uF; C0603
VS_C7, VS_C8, VS_C9, VS_C10, VS_C11, VS_C12, VS_C13, VS_C14, VS_C15: 100nF; C0603
VS_CL: 10uF; C1210
VS_CL2: 2.2nF; C0603
VS_CR: 10uF; C1210
VS_CR2: 2.2nF; C0603
VS_GBUF: 0*; R0603
VS_GND: 0*; R0603
VS_Q1: 12.288MHz; SM49
VS_R1: 1M; R0603
VS_R2, VS_R3, VS_R9, VS_R10, VS_R11, VS_R12: 100k; R0603
VS_R4, VS_R5: 22; R0603
VS_R6: 10; R0603
VS_R7, VS_R8: 10k; R0603
VS_RL: 470; R0603
VS_RR: 470; R0603

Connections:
+1V8: VS.5 (CVCC0), VS.7 (CVCC1), VS.24 (CVCC2), VS.31 (CVCC3), VS_C10.1, VS_C11.1, VS_C12.1, VS_C13.1; also elsewhere on the board
+2V8: VS.38 (AVCC0), VS.43 (AVCC1), VS.45 (AVCC2), VS_C14.1, VS_C15.1; also elsewhere on the board
+3V3: PWR.2, PWR_C1.2, VS.6 (IOVCC0), VS.14 (IOVCC1), VS.19 (IOVCC2), VS.26 (RX), VS.32 (TEST), VS_C7.1, VS_C8.1, VS_C9.1; also elsewhere on the board
+5V: PWR.1, PWR_C2.2; also elsewhere on the board
AGND: VS.37 (AGND0), VS.40 (AGND1), VS.41 (AGND2), VS.47 (AGND3), VS_C3.1, VS_C4.1, VS_C5.1, VS_C6.1, VS_C14.2, VS_C15.2, VS_CL2.2, VS_CR2.2, VS_GND.2, VS_R7.2, VS_R8.2; also elsewhere on the board
GBUF: VS.42 (GBUF), VS_GBUF.1, VS_R6.2
GND: PWR.3, PWR.4, PWR_C1.1, PWR_C2.1, VS.4 (GND0), VS.16 (GND1), VS.20 (GND2), VS.21 (GND3), VS.22 (GND4), VS.35 (GND5), VS_C1.2, VS_C2.2, VS_C7.2, VS_C8.2, VS_C9.2, VS_C10.2, VS_C11.2, VS_C12.2, VS_C13.2, VS_R2.1, VS_R3.1, VS_R9.2, VS_R10.2, VS_R11.2, VS_R12.2; also elsewhere on the board
I2S_LROUT: I2S.1, VS.36 (GPIO4), VS_R9.1
I2S_MCLK: I2S.2, VS.25 (GPIO5), VS_R10.1
I2S_SCLK: I2S.3, VS.11 (GPIO6), VS_R11.1
I2S_SDATA: I2S.4, VS.12 (GPIO7), VS_R12.1
LEFT: VS.46 (LEFT), VS_R4.2, VS_RL.1
unnamed: VS.33 (GPIO0), VS.34 (GPIO1), VS_R3.2
unnamed: VS.9 (GPIO2), VS.10 (GPIO3), VS_R2.2
unnamed: VS.18 (XTALI), VS_C2.1, VS_Q1.1, VS_R1.2
unnamed: VS.17 (XTALO), VS_C1.1, VS_Q1.2, VS_R1.1
unnamed: OUT.1, VS_GBUF.2, VS_GND.1
unnamed: OUT.3, OUT.5, VS_CR.2, VS_R7.1
unnamed: OUT.2, OUT.4, VS_CL.2, VS_R8.1
unnamed: VS_CR.1, VS_CR2.1, VS_RR.2
unnamed: VS_CL.1, VS_CL2.1, VS_RL.2
unnamed: VS_C3.2, VS_R4.1
unnamed: VS_C4.2, VS_R5.1
unnamed: VS_C5.2, VS_R6.1
RCAP: VS.44 (RCAP), VS_C6.2
RIGHT: VS.39 (RIGHT), VS_R5.2, VS_RR.1
VS_CS: VS.23 (!CS); also elsewhere on the board
VS_DCS: VS.13 (!DCS); also elsewhere on the board
VS_DREQ: VS.8 (!DREQ); also elsewhere on the board
VS_RST: VS.3 (!RESET); also elsewhere on the board
VS_SCK: VS.28 (SCLK); also elsewhere on the board
VS_SI: VS.29 (SI); also elsewhere on the board
VS_SO: VS.30 (SO); also elsewhere on the board

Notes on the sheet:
Audio Codec
www.watterott.net
Normal Line-Out
Line-Out for Headphones
VS_GND
VS_GBUF
VS_RR
VS_RL
VS_CL
VS_CR
not mounted
470
10uF
shorted
VS_CR2
VS_CL2
2.2nF
Note: For VS1033 U4 has to be a 2.5V regulator.
Line-Out = green
(Dont use with USB powered speakers)
Further Infos: VLSI AppNote: Connecting analog outputs
GND-AGND

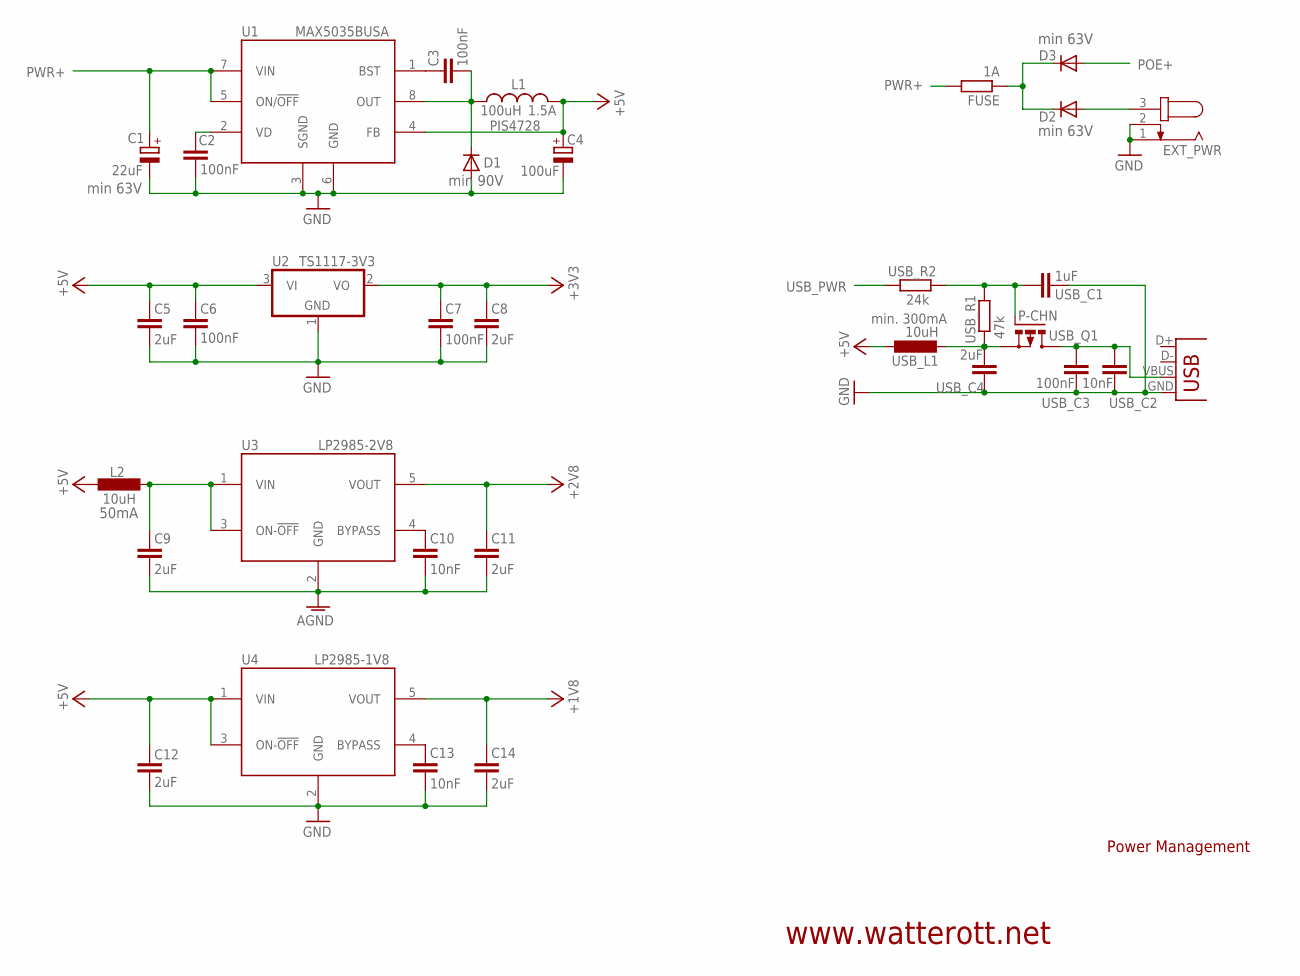
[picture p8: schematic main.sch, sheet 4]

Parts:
C1: 22uF; 153CLV-0810; VOLTAGE min 63V
C2, C3, C6, C7: 100nF; C0603
C4: 100uF; 153CLV-0810
C5, C8, C9, C11, C12, C14: 2uF; C0603
C10, C13: 10nF; C0603
D1: DIODE-DO214AA; DO214AA; VOLTAGE min 90V
D2, D3: DIODE-DO214AA; DO214AA; VOLTAGE min 63V
EXT_PWR: JACK-PLUG0; SPC4077
FUSE: 1A; R1206
L1: 100uH; CDRH
L2: 10uH; L3230M
U1: MAX5035BUSA; SO8
U2: TS1117-3V3; SOT223
U3: LP2985-2V8; SOT23-5
U4: LP2985-1V8; SOT23-5
USB: USB-A-S
USB_C1: 1uF; C0603
USB_C2: 10nF; C0603
USB_C3: 100nF; C0603
USB_C4: 2uF; C0805
USB_L1: 10uH; L3230M
USB_Q1: P-CHN; MICRO3
USB_R1: 47k; R0603
USB_R2: 24k; R0603

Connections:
5V_VIN: C9.2, L2.2, U3.1 (VIN), U3.3 (ON-!OFF)
+1V8: C14.1, U4.5 (VOUT); also elsewhere on the board
+2V8: C11.1, U3.5 (VOUT); also elsewhere on the board
+3V3: C7.1, C8.1, U2.2 (VO); also elsewhere on the board
+5V: C4.+, C5.1, C6.2, C12.2, L1.2, L2.1, U1.4 (FB), U2.3 (VI), U4.1 (VIN), U4.3 (ON-!OFF), USB_L1.1; also elsewhere on the board
AGND: C9.1, C10.2, C11.2, U3.2 (GND); also elsewhere on the board
BST: C3.1, U1.1 (BST)
GND: C1.-, C2.2, C4.-, C5.2, C6.1, C7.2, C8.2, C12.1, C13.2, C14.2, D1.A, EXT_PWR.1, EXT_PWR.2, U1.3 (SGND), U1.6 (GND), U2.1 (GND), U4.2 (GND), USB.GND, USB_C1.1, USB_C2.2, USB_C3.2, USB_C4.1; also elsewhere on the board
unnamed: USB_C4.2, USB_L1.2, USB_Q1.2 (S), USB_R1.1
unnamed: USB.VBUS, USB_C2.1, USB_C3.1, USB_Q1.3 (D)
unnamed: USB_C1.2, USB_Q1.1 (G), USB_R1.2, USB_R2.1
unnamed: D2.A, EXT_PWR.3
unnamed: D2.C, D3.C, FUSE.1
unnamed: C10.1, U3.4 (BYPASS)
unnamed: C13.1, U4.4 (BYPASS)
OUT: C3.2, D1.C, L1.1, U1.8 (OUT)
POE+: D3.A; also elsewhere on the board
PWR+: C1.+, FUSE.2, U1.5 (ON/!OFF), U1.7 (VIN); also elsewhere on the board
USB_PWR: USB_R2.2; also elsewhere on the board
VD: C2.1, U1.2 (VD)

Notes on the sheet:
Power Management
www.watterott.net
1.5A
PIS4728

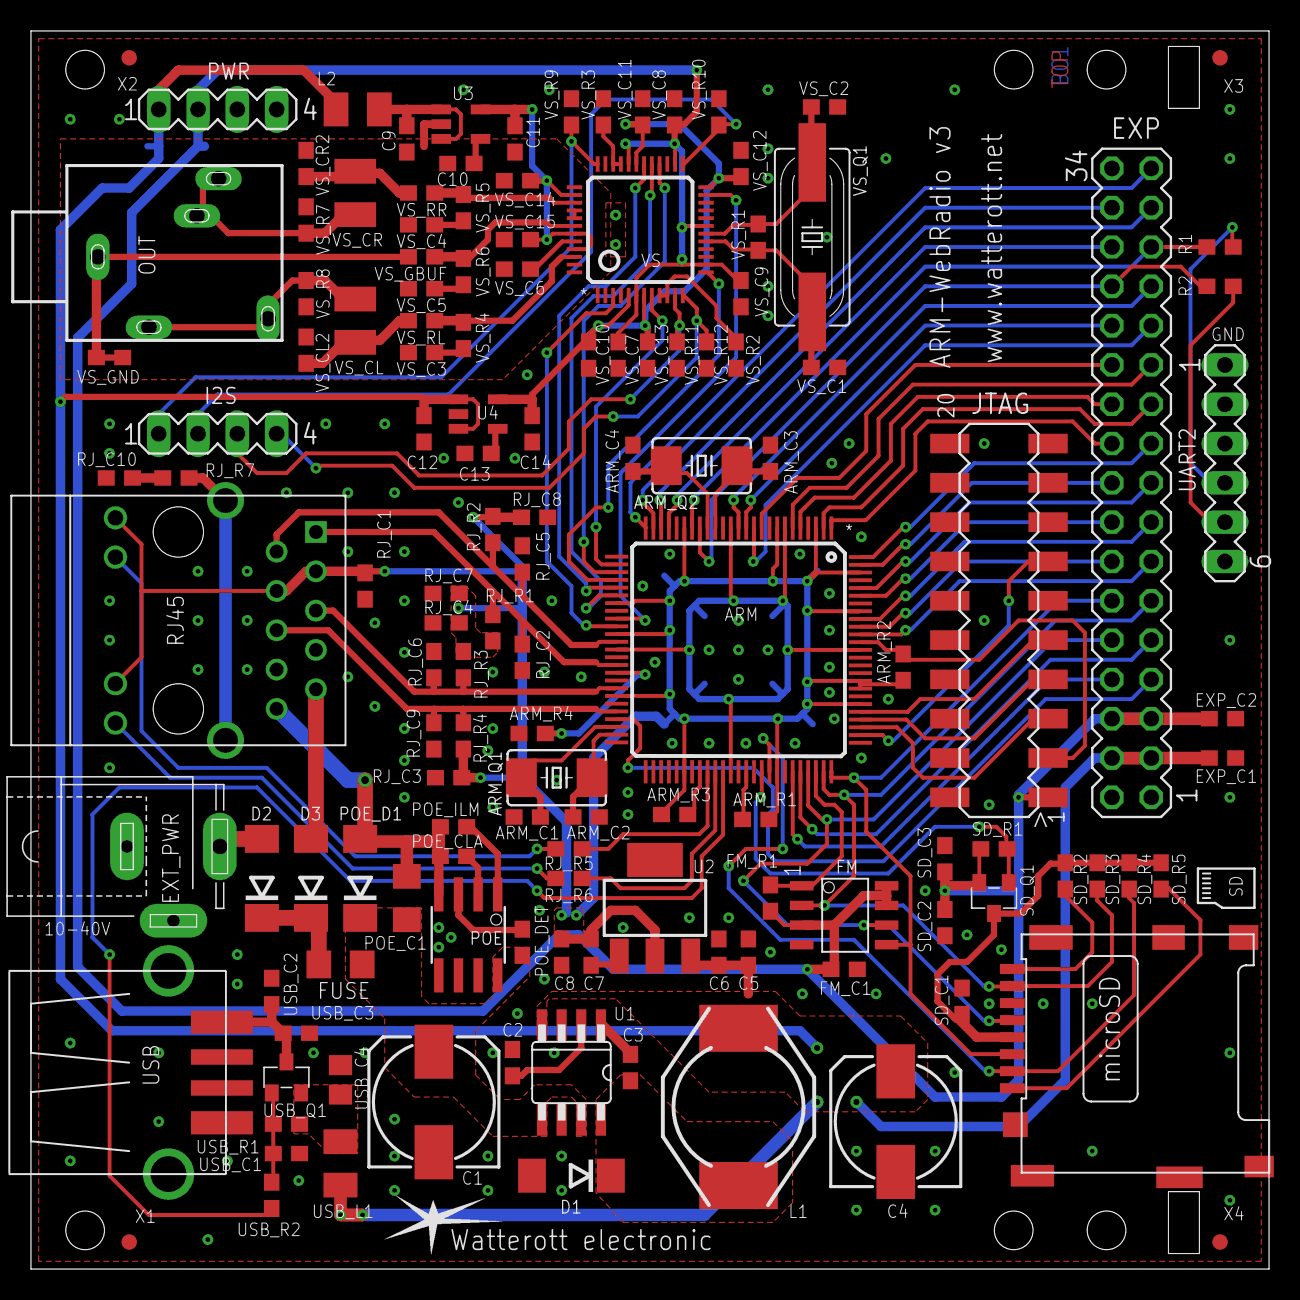
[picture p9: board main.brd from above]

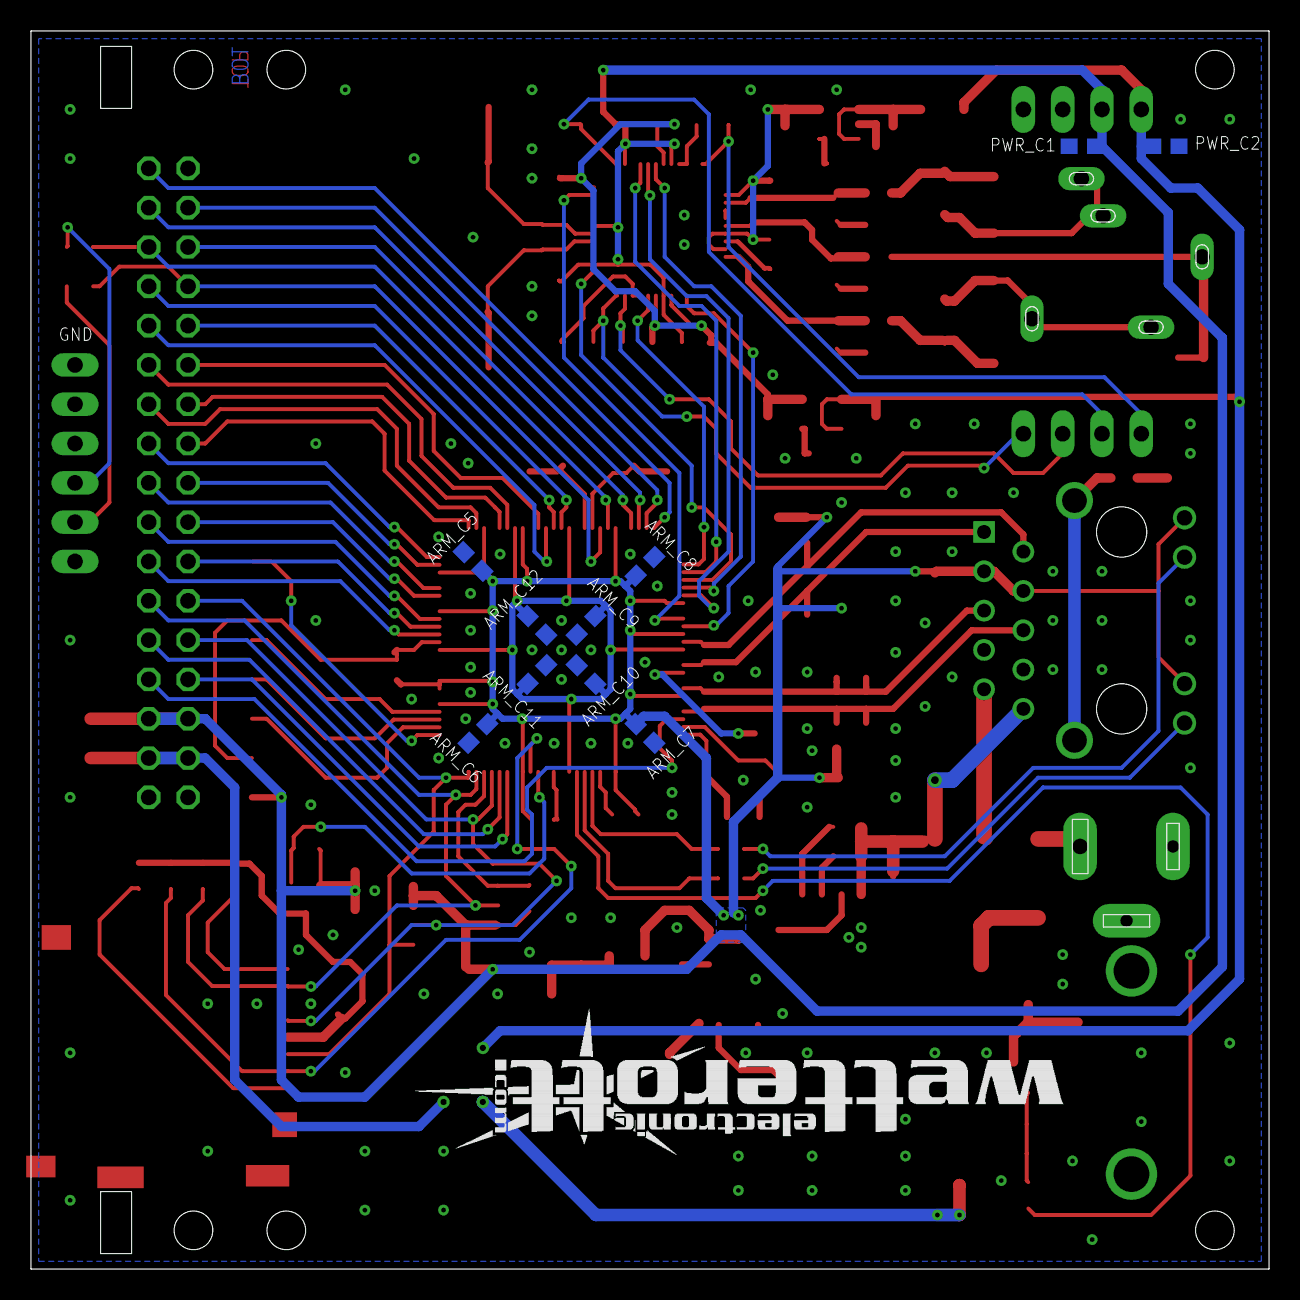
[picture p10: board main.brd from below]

Board: 2 copper layers, 80.0 x 80.0 mm, 143 parts (10 on the bottom side), 109 nets.

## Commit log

2017-01-17 KiCad conversion of main board.
    [main.kicad_pcb, main.sch, main_SS_1.sch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]
2017-01-17 KiCad conversion of display board (exp).
    [exp.kicad_pcb, exp.sch]
2017-01-25 Save "main" project in Eagle XML format
    [main.brd, main.sch]
